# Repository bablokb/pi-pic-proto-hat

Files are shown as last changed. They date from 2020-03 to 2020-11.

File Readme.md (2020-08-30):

The Pi-PIC-Proto-Hat (Version 2)
================================

Overview
--------

One of the shortcomings of the Pi is it's inability to turn off power after
shutdown. While the Pi itself only drains a small amount of power, attached
peripherals might draw a lot more. At irregular intervals, the Pi also
fails to shutdown the USB-connector, so USB-devices can really use large
amounts of power even when the Pi has shutdown.

One solution is to pull the plug, another one uses a mosfet controlled by
a microcontroller to turn power on and off. The MCU typically uses its
GPIOs to receive external signals for power on and off. In its simplest
form such a signal is just a button pulling the GPIO to ground.

The pi-pic-proto-hat provides the wiring for a PIC12F675 (MCU) and the
IRF4905 (mosfet). In addition, there is a small prototyping area for
buttons, sensors and alike.

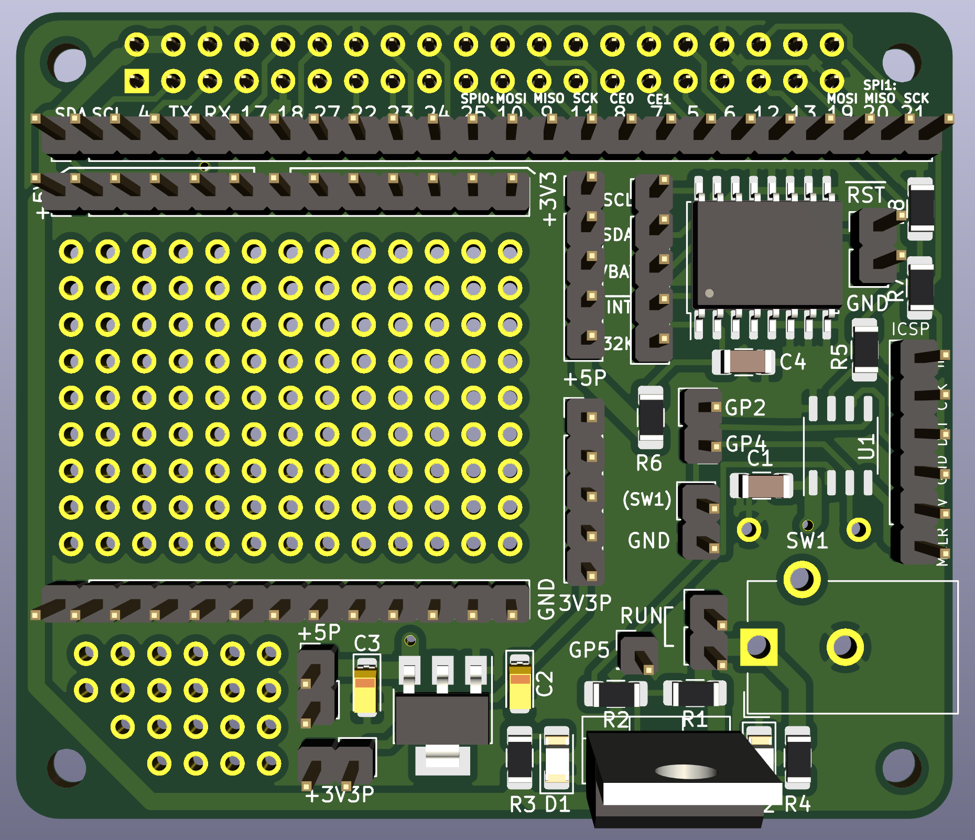
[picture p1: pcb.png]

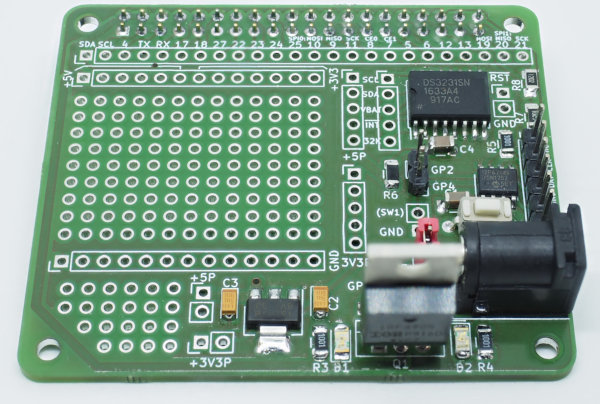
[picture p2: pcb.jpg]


If you are more familiar with a different family of MCUs (e.g. Atmega), you
should modify the design of the pcb. The Kicad-sources are in the
directory `pi-pic-proto-hat.kicad`.

Design
------

The design consists mainly of the two parts "power supply" and "PIC".
The PIC part

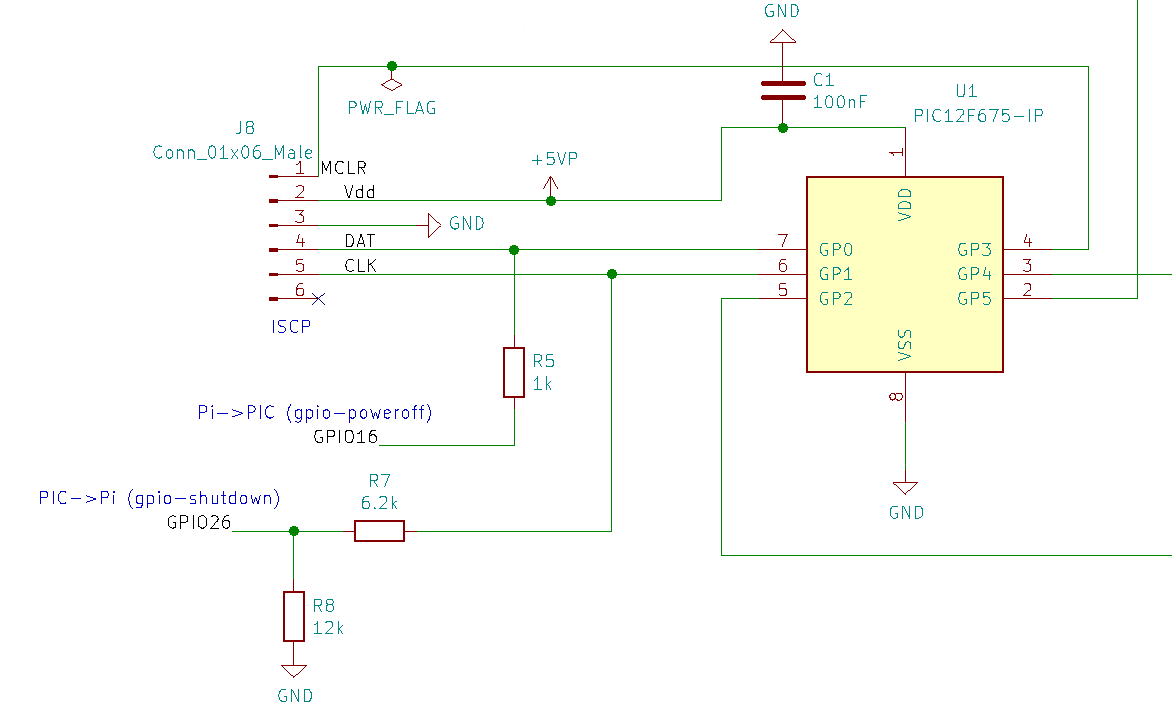
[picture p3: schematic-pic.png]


is a fairly standard implementation for the PIC featuring an
ICSP (in-circuit-programming) connector J8. GP2 and GP4 are connected to
connector, GP4 in addition to a switch and the interupt-pin of the RTC.
GP3 is only connected to the ICSP connector and unused otherwise.

If you are not using a MCU of the PIC-family, this is the part you must
modify to fit your preferred MCU.

The power-supply part



connects a barrel-jack J6 (5mm/2.1mm-type) to the mosfet, which controls
the 5V and 3.3V connectors of the Pi. J6 is also connected to J3/J11, which
give you 5V independent of the state of the Pi. In addition, if you
populate the 1117-regulator (U2), you also have permanent 3.3V on
connectors J4/J5.

The IRF4905 mosfet will switch power efficiently as long as the voltage
of the gate is high enough. The 5V of the MCU is sufficient and the
mosfet will not get too warm with the typical currents needed by a Pi.

The pcb also provides access to most of the GPIOs of the Pi. In addition,
there is a prototyping area and a number of GND-pins and power pins
(5V and 3,3V).

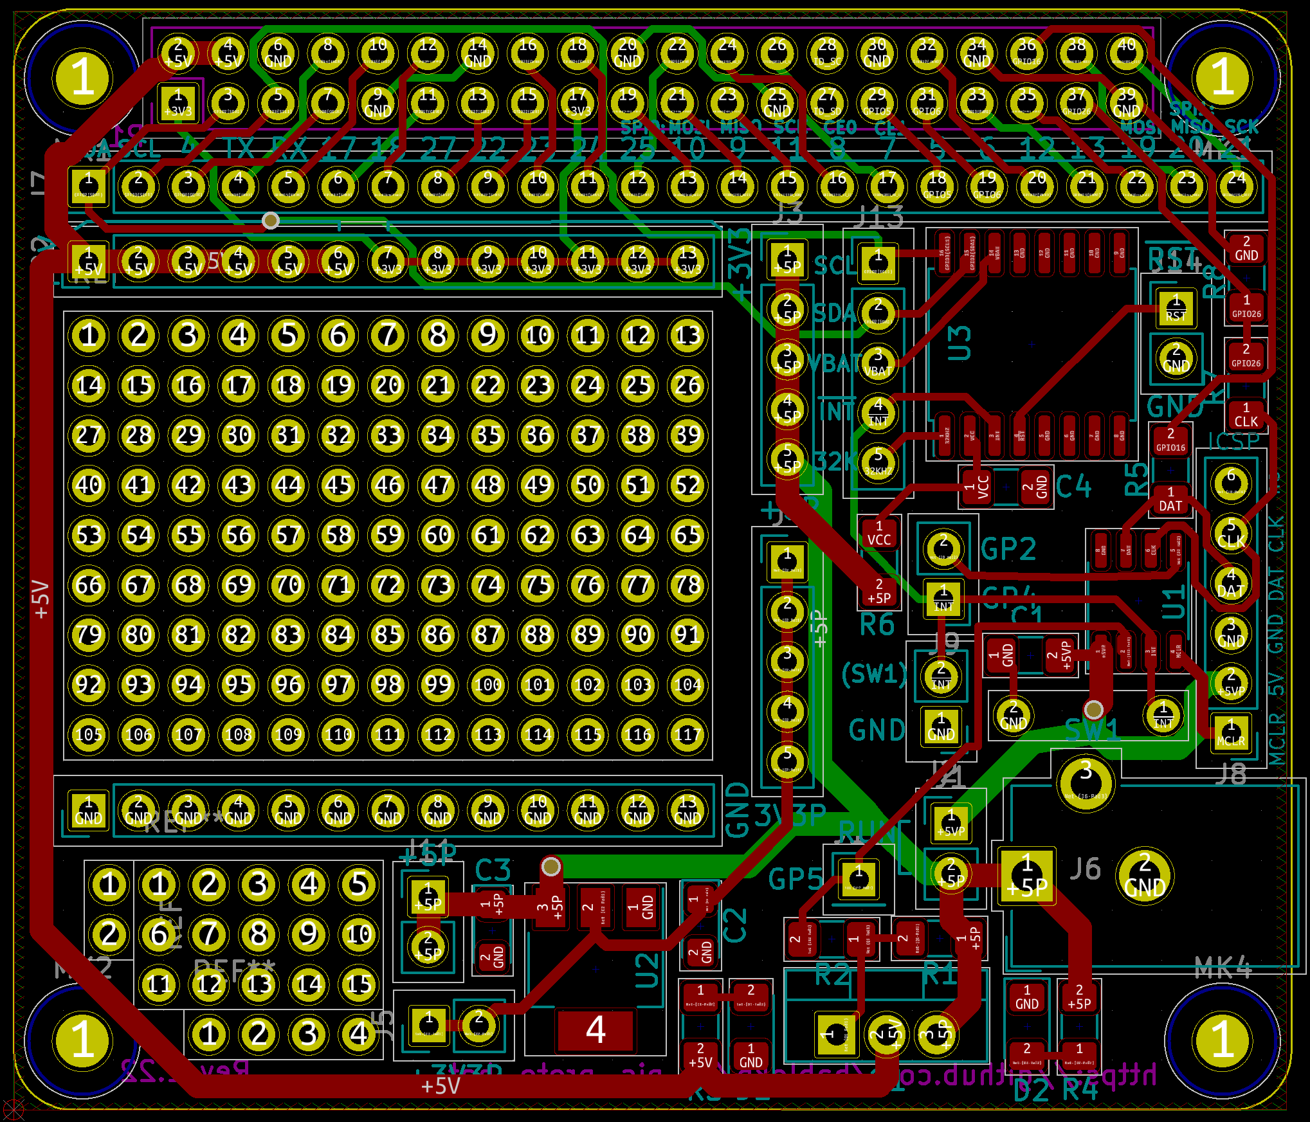
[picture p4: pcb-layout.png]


Note that the project-directory contains a Fritzing-template
(prototype-template.fzz) which is useful for prototyping:

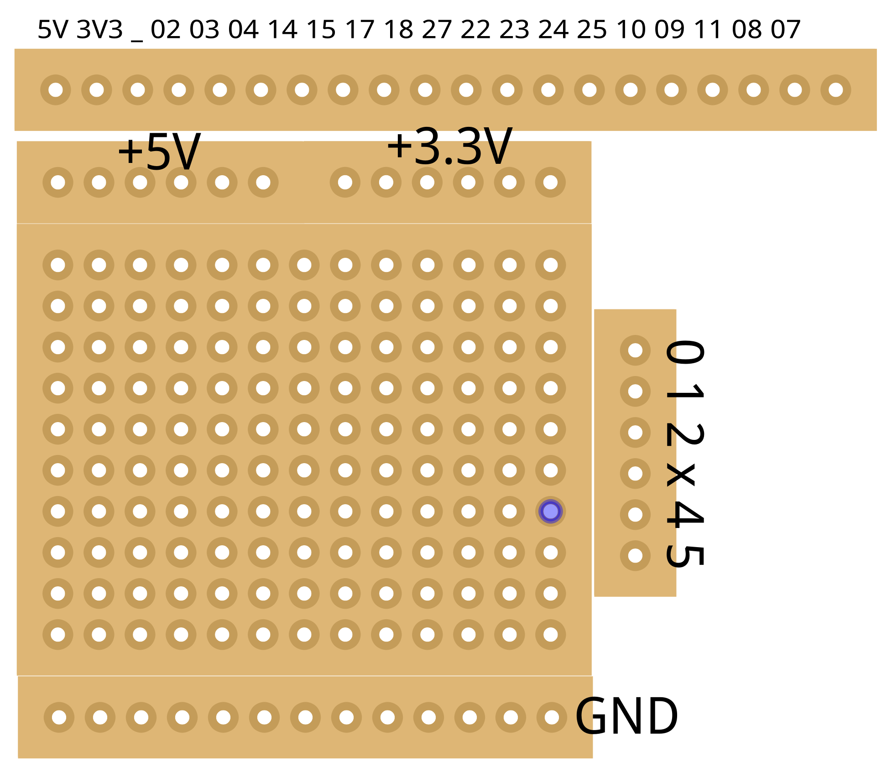
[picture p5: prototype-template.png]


Manufacturing
-------------

If your pcb-manufacturer supports Kicad directly, you can just upload the
project-file. Otherwise you have to start Kicad and export ("plot") the
gerber-files for the pcb (gerber is a universal format understood by all
manufacturers).

When you use the existing pcb-layout without any modifications, you should
make sure that you have the correct parts available. Most critical is the
barrel-jack footprint. The pcb is designed for the CUI_PJ_102AH. This part
is available e.g. from Adafruit. It looks like a normal barrel-jack adapter
but has smaller pins so you can use it directly on a breadboard.

Part-List
---------

|Part | Value | Number | Remark |
|---|---|---|---|
|C1,C4 | 100nF/50V | 2 | SMD 1206 |
|C2,C3 | 10µF | 2 | SMD 1206 Tantal |
|D1,D2 | LED | 2 | SMD 1206 |
|J1-J5,J7-13 | SL 1x40G 2,54mm | 2 | vertical |
|J6 (barral jack) | CUI_PJ_102AH | 1 | Adafruit |
|P1 (Pi-socket) | BL 2x20G 2,54mm | 1 | vertical |
|Q1 | IRF4905 | 1 | TO-220AB |
|R1,R6 | 10k | 2 | SMD 1206 |
|R2,R3,R4,R5 | 1k | 4 | SMD 1206 |
|R7 | 6.2k | 1 | SMD 1206 |
|R8 | 12k | 1 | SMD 1206 |
|SW1 | | 1 | slim switch |
|U1 | PIC12F675-IP | 1 | SO-8 |
|U2 | TLV1117-33 | 1 | SOT-223 (or AMS1117) |
|U3 | DS3231M | 1 | SOIC-16W |

Wiring
------

Not all parts are necessary, e.g. you don't need to populate the RTC
or the regulator. The two LEDs D2 (active power-supply) and D1 (power
is provided to the Pi) are also optional (together with their resistors).

You need to close jumper J1 (Run/~PGM) during normal operation. If you
flash the firmware, this jumper should be open.

Please be careful not to power the hat and the Pi at the same time.

Flashing a Firmware
-------------------

The required firmware for the PIC depends on the specific setup you choose.
In the directory [pic-firmware](./pic-firmware/Readme.md)
you will find a ready to flash hex-file for the PIC.

For flashing, you need a PICkit2-programmer, available for a few bucks from
ebay. You can flash from Linux/Raspbian with the program `pk2cmd`. The hat
has a connector for the ICSP-programmer. You should remove the jumper-shim
on J1 (connection to Pi) during programming.

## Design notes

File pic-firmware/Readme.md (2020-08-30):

Standard Firmware for Version 2
===============================

About
-----

This is a simple "firmware" for the v2 pi-pic-proto-hat:

  - The power of the Raspberry Pi is controlled by a PIC using a mosfet.
  - On a signal (high->low), the PIC sets the gate of the mosfet
    to low, thus turning on the Pi. Afterward the PIC waits for
    five seconds. This gives the Pi time to setup it's GPIOs correctly.
  - Again on a signal (high->low), the PIC requests the Pi to shutdown by
    setting an output pin to low. This pin is connected to and monitored
    by the Pi (see below).
  - The Pi now shuts down and at the end sets a pin to high (again, see below).
    This pin in turn is connected to and monitored by the PIC. The PIC
    sets the gate to high thus turning power off.

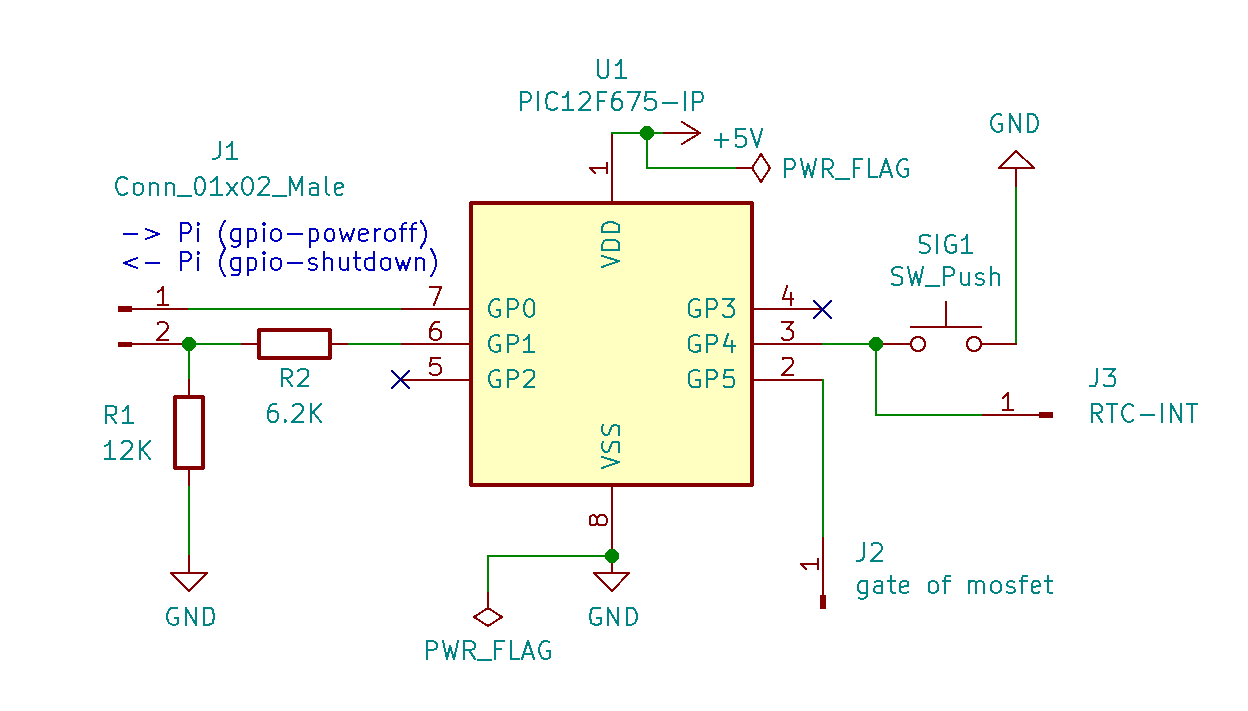
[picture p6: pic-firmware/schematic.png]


The simplest "external signal" is a button connected to the PIC and to GND.
Version 2 of the pi-pic-proto-hat connects such a button to GP4. In addition,
the RTC-interrupt pin (alarm) is also connected to GP4.

Processing of GP2 is implemented in the same way as GP2, but the pcb does
not connect anything to this pin, so it is free to use. If you modify the
firmware you could use GP2 for a different sort of input, e.g. for an
IR receiver.

*Note that the v2-pcb is not compatible with the firmware provided in the
v1-branch of this project!*

PIC Configuration
-----------------

  - GP0: PIN_FROM_PI (low->high, connected to GPIO16 on the Pi-side (physical
    pin 36). This is the same pin as in the gpio-poweroff overlay.
  - GP1: PIN_TO_PI (high->low, shutdown-request, monitored by the Pi).
    Connected to GPIO26 on the Pi-side. This is the same pin as in the 
    gpio-shutdown overlay.
  - GP2: PIN_SIG2 (high->low, second signal)
  - GP3: not connected
  - GP4: PIN_SIG1 (high->low, first signal: button, RTC)
  - GP5: PIN_POWER (connected to the gate of the mosfet)

In this scenario, the PIC should run at 5V to provide enough voltage to
the gate of the mosfet. So PIN_TO_PI needs a voltage divider when
connected to the Pi. The v2-pcb integrates this voltage devider.

Pi Configuration
----------------

On the Pi-side you have to add the following lines in your
/boot/config.xt:

    # initiate shutdown on high->low
    dtoverlay=gpio-shutdown,gpio_pin=26,gpio_pull=off
    # signal shutdown complete on low->high
    dtoverlay=gpio-poweroff,gpiopin=16

Building
--------

You need sdcc, gpasm and pk2cmd to build and flash the firmware. Please
adapt the paths within the file `rules.inc` to suit your setup.

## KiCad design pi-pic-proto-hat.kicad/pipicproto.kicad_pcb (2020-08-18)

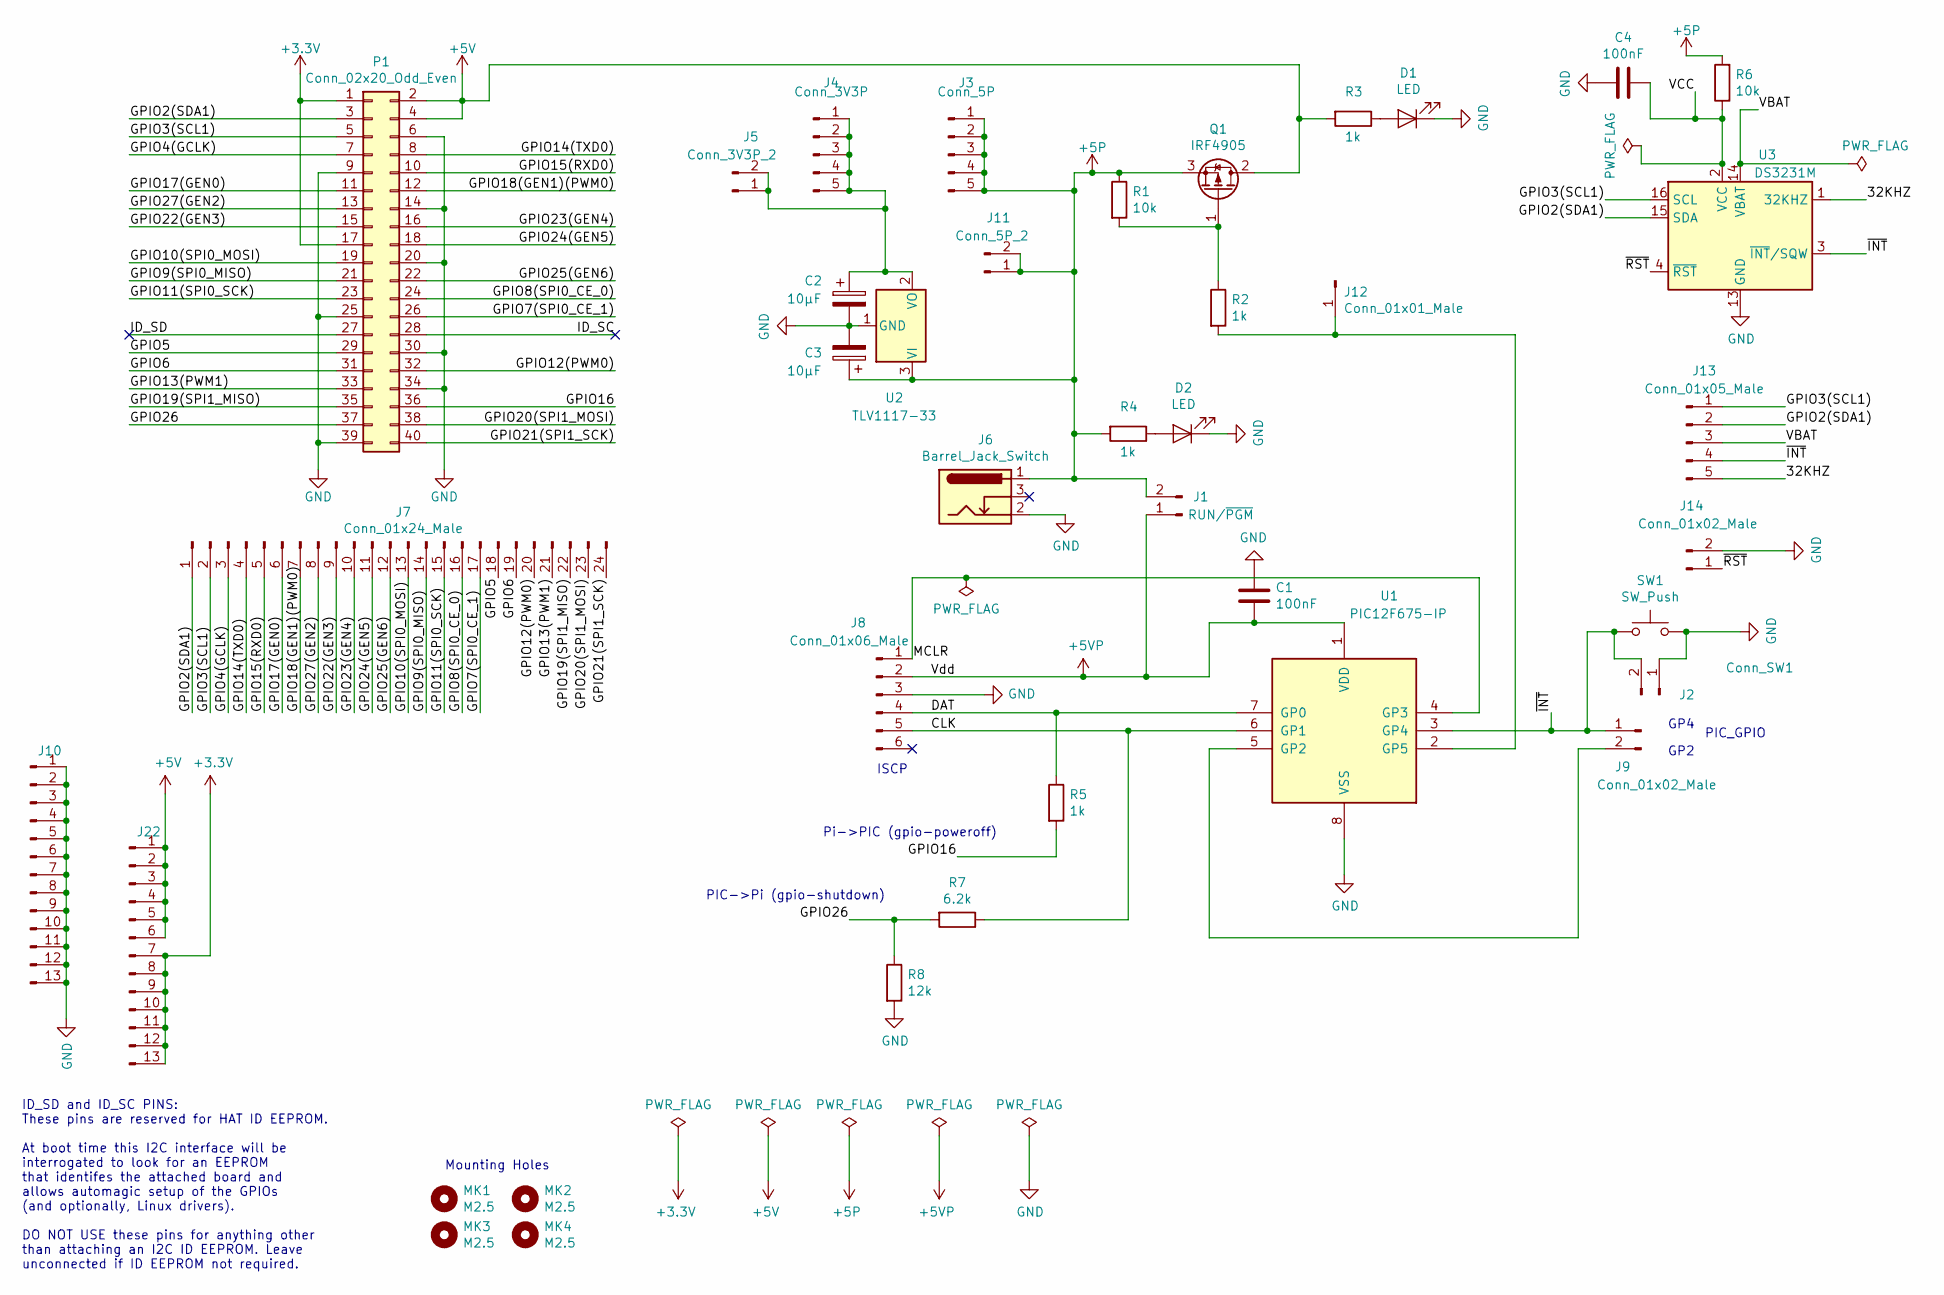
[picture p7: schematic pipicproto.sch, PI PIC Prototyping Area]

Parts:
C1, C4: 100nF; C_1206_3216Metric_Pad1.42x1.75mm_HandSolder
C2, C3: 10µF; CP_EIA-3216-18_Kemet-A
D1, D2: LED; LED_1206_3216Metric_Pad1.42x1.75mm_HandSolder
J1: RUN/~PGM~; PinHeader_1x02_P2.54mm_Vertical
J2: Conn_SW1; PinHeader_1x02_P2.54mm_Vertical
J3: Conn_5P; PinHeader_1x05_P2.54mm_Vertical
J4: Conn_3V3P; PinHeader_1x05_P2.54mm_Vertical
J5: Conn_3V3P_2; PinHeader_1x02_P2.54mm_Vertical
J6: Barrel_Jack_Switch; BarrelJack_CUI_PJ-102AH_Horizontal
J7: Conn_01x24_Male; PinHeader_1x24_P2.54mm_Vertical
J8: Conn_01x06_Male; PinHeader_1x06_P2.54mm_Vertical
J9, J14: Conn_01x02_Male; PinHeader_1x02_P2.54mm_Vertical
J10, J22: Conn_01x13_Male; PinHeader_1x13_P2.54mm_Vertical
J11: Conn_5P_2; PinHeader_1x02_P2.54mm_Vertical
J12: Conn_01x01_Male; PinHeader_1x01_P2.54mm_Vertical
J13: Conn_01x05_Male; PinHeader_1x05_P2.54mm_Vertical
MK1, MK2, MK3, MK4: M2.5; MountingHole_2.7mm_M2.5
P1: Conn_02x20_Odd_Even; PinSocket_2x20_P2.54mm_Vertical
Q1: IRF4905; TO-220-3_Vertical
R1, R6: 10k; R_1206_3216Metric_Pad1.42x1.75mm_HandSolder
R2, R3, R4, R5: 1k; R_1206_3216Metric_Pad1.42x1.75mm_HandSolder
R7: 6.2k; R_1206_3216Metric_Pad1.42x1.75mm_HandSolder
R8: 12k; R_1206_3216Metric_Pad1.42x1.75mm_HandSolder
SW1: SW_Push; SW_PUSH_SLIM_1x4
U1: PIC12F675-IP; SO-8_3.9x4.9mm_P1.27mm
U2: TLV1117-33; SOT-223
U3: DS3231M; SOIC-16W_7.5x10.3mm_P1.27mm

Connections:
+3V3: J22.7, J22.8, J22.9, J22.10, J22.11, J22.12, J22.13, P1.1, P1.17
+5P: C3.1, J1.2, J3.1, J3.2, J3.3, J3.4, J3.5, J6.1, J11.1, J11.2, Q1.3 (S), R1.1, R4.2, R6.2, U2.3 (VI)
+5V: J22.1, J22.2, J22.3, J22.4, J22.5, J22.6, P1.2, P1.4, Q1.2 (D), R3.2
+5VP: C1.2, J1.1, J8.2, U1.1 (VDD)
/32KHZ: J13.5, U3.1 (32KHZ)
/CLK: J8.5, R7.1, U1.6 (GP1)
/DAT: J8.4, R5.1, U1.7 (GP0)
/GPIO2(SDA1): J7.1, J13.2, P1.3, U3.15 (SDA)
/GPIO3(SCL1): J7.2, J13.1, P1.5, U3.16 (SCL)
/GPIO4(GCLK): J7.3, P1.7
/GPIO5: J7.18, P1.29
/GPIO6: J7.19, P1.31
/GPIO7(SPI0_CE_1): J7.17, P1.26
/GPIO8(SPI0_CE_0): J7.16, P1.24
/GPIO9(SPI0_MISO): J7.14, P1.21
/GPIO10(SPI0_MOSI): J7.13, P1.19
/GPIO11(SPI0_SCK): J7.15, P1.23
/GPIO12(PWM0): J7.20, P1.32
/GPIO13(PWM1): J7.21, P1.33
/GPIO14(TXD0): J7.4, P1.8
/GPIO15(RXD0): J7.5, P1.10
/GPIO16: P1.36, R5.2
/GPIO17(GEN0): J7.6, P1.11
/GPIO18(GEN1)(PWM0): J7.7, P1.12
/GPIO19(SPI1_MISO): J7.22, P1.35
/GPIO20(SPI1_MOSI): J7.23, P1.38
/GPIO21(SPI1_SCK): J7.24, P1.40
/GPIO22(GEN3): J7.9, P1.15
/GPIO23(GEN4): J7.10, P1.16
/GPIO24(GEN5): J7.11, P1.18
/GPIO25(GEN6): J7.12, P1.22
/GPIO26: P1.37, R7.2, R8.1
/GPIO27(GEN2): J7.8, P1.13
/ID_SC: P1.28
/ID_SD: P1.27
/MCLR: J8.1, U1.4 (GP3)
/VBAT: J13.3, U3.14 (VBAT)
/VCC: C4.1, R6.1, U3.2 (VCC)
/~INT: J2.2, J9.1, J13.4, SW1.1, U1.3 (GP4), U3.3 (~INT~/SQW)
/~RST: J14.1, U3.4 (~RST)
GND: C1.1, C2.2, C3.2, C4.2, D1.1 (K), D2.1 (K), J2.1, J6.2, J8.3, J10.1, J10.2, J10.3, J10.4, J10.5, J10.6, J10.7, J10.8, J10.9, J10.10, J10.11, J10.12, J10.13, J14.2, P1.6, P1.9, P1.14, P1.20, P1.25, P1.30, P1.34, P1.39, R8.2, SW1.2, U1.8 (VSS), U2.1 (GND), U3.5 (GND), U3.6 (GND), U3.7 (GND), U3.8 (GND), U3.9 (GND), U3.10 (GND), U3.11 (GND), U3.12 (GND), U3.13 (GND)
unnamed: C2.1, J4.1, J4.2, J4.3, J4.4, J4.5, J5.1, J5.2, U2.2 (VO)
unnamed: D1.2 (A), R3.1
unnamed: D2.2 (A), R4.1
unnamed: J9.2, U1.5 (GP2)
unnamed: J12.1, R2.2, U1.2 (GP5)
unnamed: Q1.1 (G), R1.2, R2.1

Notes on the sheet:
ID_SD and ID_SC PINS: These pins are reserved for HAT ID EEPROM. At boot time this I2C interface will be interrogated to look for an EEPROM that identifes the attached board and allows automagic setup of the GPIOs (and optionally, Linux drivers). DO NOT USE these pins for anything other than attach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
Mounting Holes
PIC_GPIO
ISCP
Pi->PIC (gpio-poweroff)
PIC->Pi (gpio-shutdown)
GP4
GP2

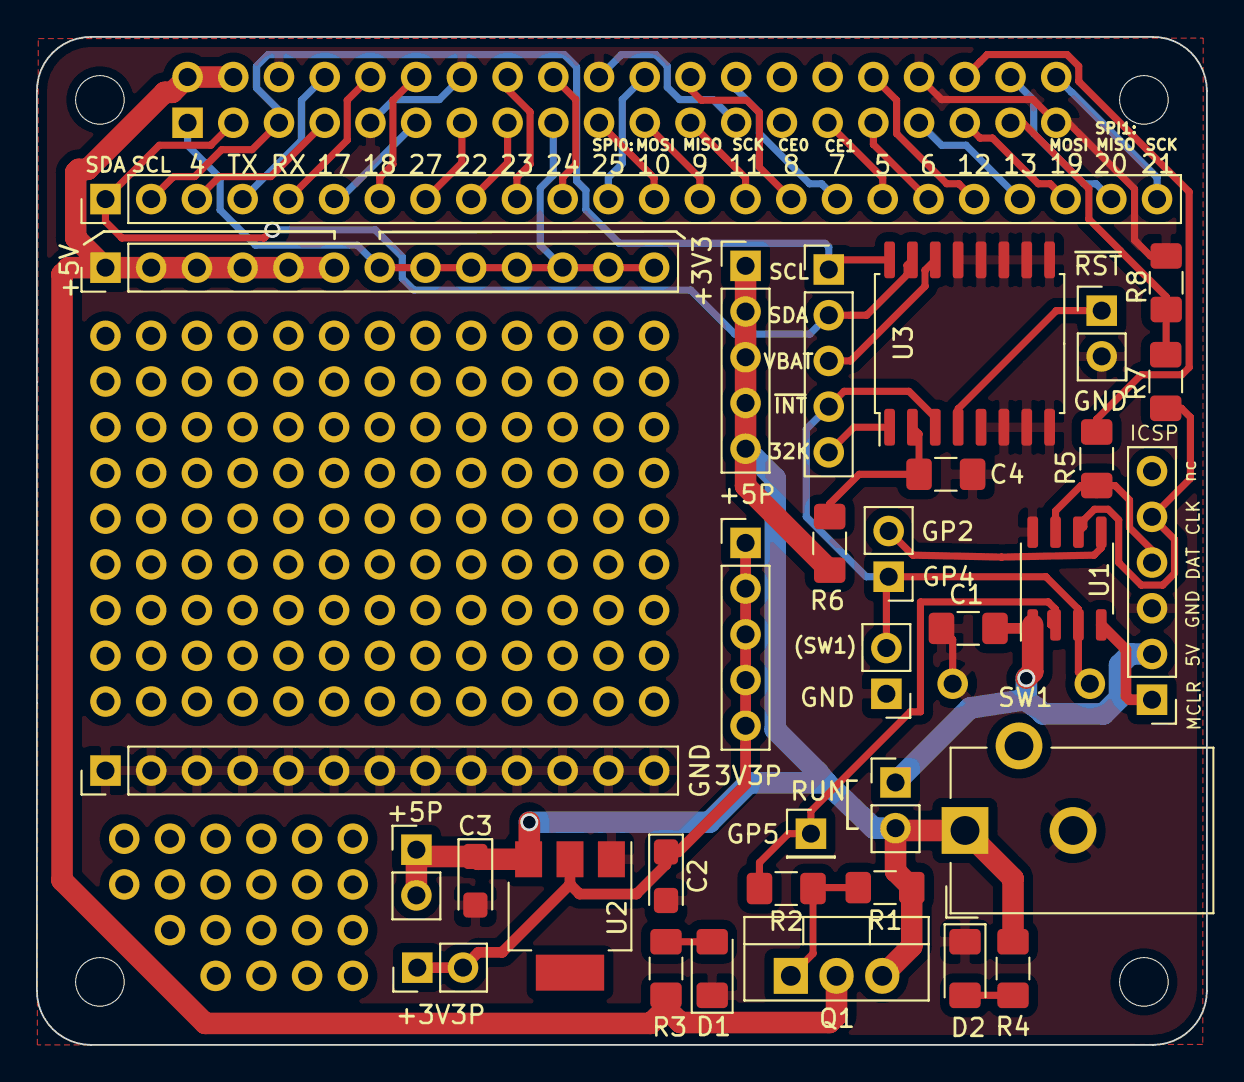
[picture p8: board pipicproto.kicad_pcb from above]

Board: 2 copper layers, 65.0 x 56.0 mm, 39 parts (1 on the bottom side), 45 nets.

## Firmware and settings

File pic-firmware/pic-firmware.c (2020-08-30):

////////////////////////////////////////////////////////////////////////
// Use the PIC to turn a Raspberry Pi on or off via a mosfet.
// 
// This project uses the following pins:
//  - PIN_POWER   (GP5): attach to gate of mosfet to turn power on or off
//  - PIN_SIG1    (GP4): external on/off signal (e.g. from button)
//  - PIN_SIG2    (GP2): external on/off signal (e.g. from button)
//  - PIN_TO_PI   (GP1): request shutdown from Pi
//  - PIN_FROM_PI (GP0): Pi confirms shutdown (PIC can turn off power)
//
// build with:
//   make build
// flash with
//   make flash
//
// Author: Bernhard Bablok (with code from Lothar Hiller)
// https://github.com/bablokb/pi-pic-proto-hat
//
////////////////////////////////////////////////////////////////////////

#define NO_BIT_DEFINES
#include <pic12f675.h>
#include <stdint.h> 
#include "quarz4MHz.h"

#define PIN_POWER   GPIObits.GP5
#define PIN_SIG1    GPIObits.GP4
#define PIN_SIG2    GPIObits.GP2
#define PIN_TO_PI   GPIObits.GP1
#define PIN_FROM_PI GPIObits.GP0
#define BOOT_WAIT   20               // 5s = 20*250ms
#define POWER_ON    0
#define POWER_OFF   1

////////////////////////////////////////////////////////////////////////
// MCLR on, Power on Timer, no WDT, int-Oscillator, 
// no brown out

__code uint16_t __at (_CONFIG) __configword = 
  _MCLRE_OFF & _PWRTE_ON & _WDT_OFF & _INTRC_OSC_NOCLKOUT & _BODEN_OFF;

////////////////////////////////////////////////////////////////////////
// Intialize registers

static void init(void) {
  // configure registers
  __asm__ ("CLRWDT");             // clear WDT even if WDT is disabled
  TRISIO    = 0b010101;           // GP4, GP2, GP0 are input
  ANSEL     = 0;                  // no analog input
  CMCON     = 0x07;               // disable comparator for GP0-GP2
  WPU       = 0b010100;           // weak pullups enable on GP2, GP4
  IOC       = 0b010101;           // IOC on GP0, GP2, GP4

  OPTION_REGbits.NOT_GPPU = 0;    // enable pullups
  GPIO                    = 0;    // initial value of GPIOs
  PIN_POWER       = POWER_OFF;    //  except PIN_POWER
  PIN_TO_PI               = 1;    //  except PIN_TO_PI
  INTCON                  = 0;    // clear interrupt flag bits
  INTCONbits.GPIE         = 1;    // enable IOC
  INTCONbits.GIE          = 1;    // global interrupt enable
}

////////////////////////////////////////////////////////////////////////
// Interrupt service routine

static void isr(void) __interrupt 0 {
  if (INTCONbits.GPIF) {                  // interrupt-on-change
    if (!PIN_SIG1||!PIN_SIG2) {           // SIG1 or SIG2 is low
      if (PIN_POWER == POWER_OFF) {       // power is off:
        PIN_POWER = POWER_ON;             //   turn power on and
        maxitime(BOOT_WAIT);              //   wait until Pi is up
      } else {                            // power is on:
        PIN_TO_PI = 0;                    //   signal shutdown to Pi
      }
    } else if (PIN_FROM_PI) {             // High: shutdown complete
      PIN_POWER = POWER_OFF;              // turn power off
      PIN_TO_PI = 1;                      // and restore initial state
    }
    INTCONbits.GPIF = 0;                  // clear IOC interrupt flag
  }
  maxitime(1);  // wait 250ms (debounce)
}

////////////////////////////////////////////////////////////////////////
// main program (boring)
//   - calibrate internal clock
//   - initialize registers
//   - go to sleep

void main(void) {
  // Load calibration
  __asm
    bsf  STATUS, RP0
    call 0x3ff    ; read value
    movwf OSCCAL  ; set value
    bcf  STATUS, RP0
  __endasm;

  init();
  while (1) {
    __asm__("SLEEP");
  }
}

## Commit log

2020-02-17 version-a: initial commit
    [pipicproto.kicad_pcb, pipicproto.sch]
2020-02-17 version-f (F.Cu filled, B.SilkS labels)
    [pipicproto.kicad_pcb, pipicproto.sch]
2020-02-22 renamed (and moved) directory kicad/pi-pic-proto-hat to pi-pic-proto-hat.kicad
    [pipicproto.kicad_pcb, pipicproto.sch]
2020-03-09 updated version with wait after power-on
2020-03-10 added descriptive text
    [pipicproto.sch]
2020-03-11 moved directory
    [example-setup.kicad_pcb, example-setup.sch]
2020-03-11 moved labels
    [prototype-template.fzz]
2020-03-11 added description of prototype template
2020-03-12 bugfix: power is on if gate is low
2020-03-12 also link to pcb.jpg
2020-06-22 fix: changed label ISCP to ICSP
    [pipicproto.kicad_pcb]
2020-06-22 V2.01: removed J4/J5/prototyping area
    [pipicproto.kicad_pcb, pipicproto.sch]
2020-06-22 V2.02: connect GP0/GP1 directly to the Pi (add voltage-divider for GP1)
    [pipicproto.kicad_pcb, pipicproto.sch]
2020-06-22 V2.03: removed reset-button, pullup, bat85
    [pipicproto.kicad_pcb, pipicproto.sch]
2020-06-22 moved voltage-divider to free area above PIC
    [pipicproto.kicad_pcb]
2020-06-22 V2.04: place jumper J1 between J6 (barrel-jack) and ICSP-connector
    [pipicproto.kicad_pcb, pipicproto.sch]
2020-06-29 V2.06: remove R6 (not needed, since we added a voltage-divider)
    [pipicproto.kicad_pcb, pipicproto.sch]
2020-07-03 V2.07: remove J2/J3 connectors
    [pipicproto.kicad_pcb, pipicproto.sch]
2020-07-03 V2.08: migrate to SMD for PIC
    [pipicproto.kicad_pcb, pipicproto.sch]
2020-07-03 V2.09: rotated ICSP-header to optimze layout
    [pipicproto.kicad_pcb, pipicproto.sch]
2020-07-03 V2.10: changed place of GP2/GP4 header
    [pipicproto.kicad_pcb, pipicproto.sch]
2020-07-17 moved R7/R8 to top right
    [pipicproto.kicad_pcb]
2020-07-17 moved R5/PIC next to ICSP
    [pipicproto.kicad_pcb]
2020-07-18 V2.11: added LEDs
    [pipicproto.kicad_pcb, pipicproto.sch]
2020-07-18 V2.12: changed position of RUN-jumper
    [pipicproto.kicad_pcb, pipicproto.sch]
2020-07-23 V2.13: added button connected to GP2
    [pipicproto.kicad_pcb, pipicproto.sch]
2020-07-23 moved button to right of power-jack
    [pipicproto.kicad_pcb]
2020-07-24 V2.14: removed dead button from power connector
    [pipicproto.kicad_pcb, pipicproto.sch]
2020-07-24 V2.15: added connector for +5P (5V permanently on)
    [pipicproto.kicad_pcb, pipicproto.sch]
2020-07-24 V2.16: added regulator and connector for +3V3P (3V3 permanently on)
    [pipicproto.kicad_pcb, pipicproto.sch]
2020-07-25 V2.17: connect switch to GP4 instead of GP2
    [pipicproto.kicad_pcb, pipicproto.sch]
2020-07-25 added prototyping area
    [pipicproto.kicad_pcb]
2020-07-25 V2.18: add 5VP and 3V3P connectors bottom left
    [pipicproto.kicad_pcb, pipicproto.sch]
2020-07-25 added prototyping area bottom left
    [pipicproto.kicad_pcb]
2020-07-25 V2.19: add GP5 connector
    [pipicproto.kicad_pcb, pipicproto.sch]
2020-07-30 V2.20: added DS3231
    [pipicproto.kicad_pcb, pipicproto.sch]
2020-08-01 V2.21: added 32KHZ-pin of RTC to connector
    [pipicproto.kicad_pcb, pipicproto.sch]
2020-08-01 V2.22: added RST/GND connector for RTC
    [pipicproto.kicad_pcb, pipicproto.sch]
2020-08-12 moved some labels
    [pipicproto.kicad_pcb]
2020-08-18 fixed label on bottom
    [pipicproto.kicad_pcb]
2020-08-22 non-functional changes to layout
    [pipicproto.sch]
2020-08-30 not relevant for v2
    [example-setup.fzz, example-setup.kicad_pcb, example-setup.sch]
2020-08-30 removed temporarily
    [prototype-template.fzz]
2020-08-30 link to schematic
